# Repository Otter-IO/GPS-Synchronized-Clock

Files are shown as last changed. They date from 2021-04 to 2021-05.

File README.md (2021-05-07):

# GPS-Synchronized-Clock
This is an FPGA based GPS Synchronized Clock. It utilizes an Intel 10M02SCE144 single supply FPGA with integrated configuration memory.

The clock is split into 2 pieces, the FPGA board and the clock display. This was done so that to FPGA board could be used for other projects easily without redesign. It also allowed me to use a 4-layer board for the FPGA and a 2-layer board for the clock display. This helped keep costs low while also getting the advantages of a 4-layer board for the FPGA. The boards were designed using KiCAD.

The code is written in Verilog and is split into multiple modules to allow for easy modification and reuse. The bitstream files for the FPGA were generated using the free version of Intel Quartus Prime. The entire project is included for your use.

The code is by no means perfect. I’m still learning Verilog and there are certainly optimizations that could be made, especially with the SDC timing file. If you have more experience with FPGAs feel free to improve the design.

See the final product on YouTube: https://www.youtube.com/watch?v=TpDHRGk3vro

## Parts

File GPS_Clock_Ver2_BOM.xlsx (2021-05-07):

Ref | Value | Description | KiCAD Footprint
DS1 | 7_Segment | 0.56" CC Seven Segment Display | Custom_Parts:0.56_CC_7_Segment_Display
DS2 | 7_Segment | 0.56" CC Seven Segment Display | Custom_Parts:0.56_CC_7_Segment_Display
DS3 | 7_Segment | 0.56" CC Seven Segment Display | Custom_Parts:0.56_CC_7_Segment_Display
DS4 | 7_Segment | 0.56" CC Seven Segment Display | Custom_Parts:0.56_CC_7_Segment_Display
DS5 | 7_Segment | 0.56" CC Seven Segment Display | Custom_Parts:0.56_CC_7_Segment_Display
DS6 | 7_Segment | 0.56" CC Seven Segment Display | Custom_Parts:0.56_CC_7_Segment_Display
DS7 | 7_Segment | 0.56" CC Seven Segment Display | Custom_Parts:0.56_CC_7_Segment_Display
DS8 | 7_Segment | 0.56" CC Seven Segment Display | Custom_Parts:0.56_CC_7_Segment_Display
DS9 | 7_Segment | 0.56" CC Seven Segment Display | Custom_Parts:0.56_CC_7_Segment_Display
J2 | IO Pins | 2.54mm Female Pin Headers | Connector_PinHeader_2.54mm:PinHeader_2x20_P2.54mm_Vertical
J4 | IO Pins | 2.54mm Female Pin Headers | Connector_PinHeader_2.54mm:PinHeader_2x20_P2.54mm_Vertical
J3 | IO Pins | 2.54mm Female Pin Headers | Connector_PinHeader_2.54mm:PinHeader_2x14_P2.54mm_Vertical
J1 | 5V Power | 2.54mm Female Pin Headers | Connector_PinHeader_2.54mm:PinHeader_2x02_P2.54mm_Vertical
R1 | 220 | 0805 Resistor | Resistor_SMD:R_0805_2012Metric_Pad1.20x1.40mm_HandSolder
R3 | 220 | 0805 Resistor | Resistor_SMD:R_0805_2012Metric_Pad1.20x1.40mm_HandSolder
R5 | 220 | 0805 Resistor | Resistor_SMD:R_0805_2012Metric_Pad1.20x1.40mm_HandSolder
R7 | 220 | 0805 Resistor | Resistor_SMD:R_0805_2012Metric_Pad1.20x1.40mm_HandSolder
R8 | 220 | 0805 Resistor | Resistor_SMD:R_0805_2012Metric_Pad1.20x1.40mm_HandSolder
R10 | 220 | 0805 Resistor | Resistor_SMD:R_0805_2012Metric_Pad1.20x1.40mm_HandSolder
R17 | 220 | 0805 Resistor | Resistor_SMD:R_0805_2012Metric_Pad1.20x1.40mm_HandSolder
R12 | 220 | 0805 Resistor | Resistor_SMD:R_0805_2012Metric_Pad1.20x1.40mm_HandSolder
R14 | 220 | 0805 Resistor | Resistor_SMD:R_0805_2012Metric_Pad1.20x1.40mm_HandSolder
R19 | 220 | 0805 Resistor | Resistor_SMD:R_0805_2012Metric_Pad1.20x1.40mm_HandSolder
R21 | 220 | 0805 Resistor | Resistor_SMD:R_0805_2012Metric_Pad1.20x1.40mm_HandSolder
R23 | 220 | 0805 Resistor | Resistor_SMD:R_0805_2012Metric_Pad1.20x1.40mm_HandSolder
R24 | 220 | 0805 Resistor | Resistor_SMD:R_0805_2012Metric_Pad1.20x1.40mm_HandSolder
R26 | 220 | 0805 Resistor | Resistor_SMD:R_0805_2012Metric_Pad1.20x1.40mm_HandSolder
R33 | 220 | 0805 Resistor | Resistor_SMD:R_0805_2012Metric_Pad1.20x1.40mm_HandSolder
R28 | 220 | 0805 Resistor | Resistor_SMD:R_0805_2012Metric_Pad1.20x1.40mm_HandSolder
R30 | 220 | 0805 Resistor | Resistor_SMD:R_0805_2012Metric_Pad1.20x1.40mm_HandSolder
R35 | 220 | 0805 Resistor | Resistor_SMD:R_0805_2012Metric_Pad1.20x1.40mm_HandSolder
R37 | 220 | 0805 Resistor | Resistor_SMD:R_0805_2012Metric_Pad1.20x1.40mm_HandSolder
R39 | 220 | 0805 Resistor | Resistor_SMD:R_0805_2012Metric_Pad1.20x1.40mm_HandSolder
R40 | 220 | 0805 Resistor | Resistor_SMD:R_0805_2012Metric_Pad1.20x1.40mm_HandSolder
R42 | 220 | 0805 Resistor | Resistor_SMD:R_0805_2012Metric_Pad1.20x1.40mm_HandSolder
R44 | 220 | 0805 Resistor | Resistor_SMD:R_0805_2012Metric_Pad1.20x1.40mm_HandSolder
R46 | 220 | 0805 Resistor | Resistor_SMD:R_0805_2012Metric_Pad1.20x1.40mm_HandSolder
R48 | 220 | 0805 Resistor | Resistor_SMD:R_0805_2012Metric_Pad1.20x1.40mm_HandSolder
R50 | 220 | 0805 Resistor | Resistor_SMD:R_0805_2012Metric_Pad1.20x1.40mm_HandSolder
R52 | 220 | 0805 Resistor | Resistor_SMD:R_0805_2012Metric_Pad1.20x1.40mm_HandSolder
R54 | 220 | 0805 Resistor | Resistor_SMD:R_0805_2012Metric_Pad1.20x1.40mm_HandSolder
R55 | 220 | 0805 Resistor | Resistor_SMD:R_0805_2012Metric_Pad1.20x1.40mm_HandSolder
R57 | 220 | 0805 Resistor | Resistor_SMD:R_0805_2012Metric_Pad1.20x1.40mm_HandSolder
R59 | 220 | 0805 Resistor | Resistor_SMD:R_0805_2012Metric_Pad1.20x1.40mm_HandSolder
R61 | 220 | 0805 Resistor | Resistor_SMD:R_0805_2012Metric_Pad1.20x1.40mm_HandSolder
R62 | 220 | 0805 Resistor | Resistor_SMD:R_0805_2012Metric_Pad1.20x1.40mm_HandSolder
R64 | 220 | 0805 Resistor | Resistor_SMD:R_0805_2012Metric_Pad1.20x1.40mm_HandSolder
R66 | 220 | 0805 Resistor | Resistor_SMD:R_0805_2012Metric_Pad1.20x1.40mm_HandSolder
R68 | 220 | 0805 Resistor | Resistor_SMD:R_0805_2012Metric_Pad1.20x1.40mm_HandSolder
R2 | 220 | 0805 Resistor | Resistor_SMD:R_0805_2012Metric_Pad1.20x1.40mm_HandSolder
R4 | 220 | 0805 Resistor | Resistor_SMD:R_0805_2012Metric_Pad1.20x1.40mm_HandSolder
R6 | 220 | 0805 Resistor | Resistor_SMD:R_0805_2012Metric_Pad1.20x1.40mm_HandSolder
R9 | 220 | 0805 Resistor | Resistor_SMD:R_0805_2012Metric_Pad1.20x1.40mm_HandSolder
R11 | 220 | 0805 Resistor | Resistor_SMD:R_0805_2012Metric_Pad1.20x1.40mm_HandSolder
R13 | 220 | 0805 Resistor | Resistor_SMD:R_0805_2012Metric_Pad1.20x1.40mm_HandSolder
R18 | 220 | 0805 Resistor | Resistor_SMD:R_0805_2012Metric_Pad1.20x1.40mm_HandSolder
R20 | 220 | 0805 Resistor | Resistor_SMD:R_0805_2012Metric_Pad1.20x1.40mm_HandSolder
R22 | 220 | 0805 Resistor | Resistor_SMD:R_0805_2012Metric_Pad1.20x1.40mm_HandSolder
R25 | 220 | 0805 Resistor | Resistor_SMD:R_0805_2012Metric_Pad1.20x1.40mm_HandSolder
R27 | 220 | 0805 Resistor | Resistor_SMD:R_0805_2012Metric_Pad1.20x1.40mm_HandSolder
R29 | 220 | 0805 Resistor | Resistor_SMD:R_0805_2012Metric_Pad1.20x1.40mm_HandSolder
R34 | 220 | 0805 Resistor | Resistor_SMD:R_0805_2012Metric_Pad1.20x1.40mm_HandSolder
R36 | 220 | 0805 Resistor | Resistor_SMD:R_0805_2012Metric_Pad1.20x1.40mm_HandSolder
R38 | 220 | 0805 Resistor | Resistor_SMD:R_0805_2012Metric_Pad1.20x1.40mm_HandSolder
R41 | 220 | 0805 Resistor | Resistor_SMD:R_0805_2012Metric_Pad1.20x1.40mm_HandSolder
R43 | 220 | 0805 Resistor | Resistor_SMD:R_0805_2012Metric_Pad1.20x1.40mm_HandSolder
R45 | 220 | 0805 Resistor | Resistor_SMD:R_0805_2012Metric_Pad1.20x1.40mm_HandSolder
R49 | 220 | 0805 Resistor | Resistor_SMD:R_0805_2012Metric_Pad1.20x1.40mm_HandSolder
R51 | 220 | 0805 Resistor | Resistor_SMD:R_0805_2012Metric_Pad1.20x1.40mm_HandSolder
R53 | 220 | 0805 Resistor | Resistor_SMD:R_0805_2012Metric_Pad1.20x1.40mm_HandSolder
R56 | 220 | 0805 Resistor | Resistor_SMD:R_0805_2012Metric_Pad1.20x1.40mm_HandSolder
R58 | 220 | 0805 Resistor | Resistor_SMD:R_0805_2012Metric_Pad1.20x1.40mm_HandSolder
R60 | 220 | 0805 Resistor | Resistor_SMD:R_0805_2012Metric_Pad1.20x1.40mm_HandSolder
R63 | 220 | 0805 Resistor | Resistor_SMD:R_0805_2012Metric_Pad1.20x1.40mm_HandSolder
R65 | 220 | 0805 Resistor | Resistor_SMD:R_0805_2012Metric_Pad1.20x1.40mm_HandSolder
R67 | 220 | 0805 Resistor | Resistor_SMD:R_0805_2012Metric_Pad1.20x1.40mm_HandSolder
R47 | 220 | 0805 Resistor | Resistor_SMD:R_0805_2012Metric_Pad1.20x1.40mm_HandSolder
D1 | LED | 3mm LED | LED_THT:LED_D3.0mm
D2 | LED | 3mm LED | LED_THT:LED_D3.0mm
D3 | LED | 3mm LED | LED_THT:LED_D3.0mm
D4 | LED | 3mm LED | LED_THT:LED_D3.0mm
R15 | 220 | 0805 Resistor | Resistor_SMD:R_0805_2012Metric_Pad1.20x1.40mm_HandSolder
R16 | 220 | 0805 Resistor | Resistor_SMD:R_0805_2012Metric_Pad1.20x1.40mm_HandSolder
R31 | 220 | 0805 Resistor | Resistor_SMD:R_0805_2012Metric_Pad1.20x1.40mm_HandSolder
R32 | 220 | 0805 Resistor | Resistor_SMD:R_0805_2012Metric_Pad1.20x1.40mm_HandSolder
S1 | Tact_Switch | Generic Tact Switch | Custom_Parts:THT_Tact_Switch
S2 | Tact_Switch | Generic Tact Switch | Custom_Parts:THT_Tact_Switch
S3 | Tact_Switch | Generic Tact Switch | Custom_Parts:THT_Tact_Switch
R69 | 10k | 0603 Resistor | Resistor_SMD:R_0603_1608Metric_Pad0.98x0.95mm_HandSolder
R70 | 10k | 0603 Resistor | Resistor_SMD:R_0603_1608Metric_Pad0.98x0.95mm_HandSolder
R71 | 10k | 0603 Resistor | Resistor_SMD:R_0603_1608Metric_Pad0.98x0.95mm_HandSolder
J5 | GPS Module | Generic GPS Module (Get Pinout From PCB) | Connector_PinHeader_2.54mm:PinHeader_1x05_P2.54mm_Vertical
D5 | LED | 3mm LED | LED_THT:LED_D3.0mm
R72 | 220 | 0805 Resistor | Resistor_SMD:R_0805_2012Metric_Pad1.20x1.40mm_HandSolder

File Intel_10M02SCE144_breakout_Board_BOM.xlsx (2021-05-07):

Ref | Value | Description | KiCAD Footprint
C1 | 10uF | Electrolytic Through Hole Capacitor | Capacitor_THT:CP_Radial_D4.0mm_P2.00mm
C10 | 0.1uF | 0603 Ceramic Capacitor | Capacitor_SMD:C_0603_1608Metric_Pad1.08x0.95mm_HandSolder
C11 | 0.1uF | 0603 Ceramic Capacitor | Capacitor_SMD:C_0603_1608Metric_Pad1.08x0.95mm_HandSolder
C12 | 1uF | 0603 Ceramic Capacitor | Capacitor_SMD:C_0603_1608Metric_Pad1.08x0.95mm_HandSolder
C13 | 0.1uF | 0603 Ceramic Capacitor | Capacitor_SMD:C_0603_1608Metric_Pad1.08x0.95mm_HandSolder
C14 | 1uF | 0603 Ceramic Capacitor | Capacitor_SMD:C_0603_1608Metric_Pad1.08x0.95mm_HandSolder
C15 | 0.1uF | 0603 Ceramic Capacitor | Capacitor_SMD:C_0603_1608Metric_Pad1.08x0.95mm_HandSolder
C16 | 1uF | 0603 Ceramic Capacitor | Capacitor_SMD:C_0603_1608Metric_Pad1.08x0.95mm_HandSolder
C17 | 0.1uF | 0603 Ceramic Capacitor | Capacitor_SMD:C_0603_1608Metric_Pad1.08x0.95mm_HandSolder
C18 | 1uF | 0603 Ceramic Capacitor | Capacitor_SMD:C_0603_1608Metric_Pad1.08x0.95mm_HandSolder
C19 | 0.1uF | 0603 Ceramic Capacitor | Capacitor_SMD:C_0603_1608Metric_Pad1.08x0.95mm_HandSolder
C2 | 10uF | Electrolytic Through Hole Capacitor | Capacitor_THT:CP_Radial_D4.0mm_P2.00mm
C20 | 1uF | 0603 Ceramic Capacitor | Capacitor_SMD:C_0603_1608Metric_Pad1.08x0.95mm_HandSolder
C21 | 0.1uF | 0603 Ceramic Capacitor | Capacitor_SMD:C_0603_1608Metric_Pad1.08x0.95mm_HandSolder
C22 | 1uF | 0603 Ceramic Capacitor | Capacitor_SMD:C_0603_1608Metric_Pad1.08x0.95mm_HandSolder
C23 | 0.1uF | 0603 Ceramic Capacitor | Capacitor_SMD:C_0603_1608Metric_Pad1.08x0.95mm_HandSolder
C24 | 1uF | 0603 Ceramic Capacitor | Capacitor_SMD:C_0603_1608Metric_Pad1.08x0.95mm_HandSolder
C25 | 0.1uF | 0603 Ceramic Capacitor | Capacitor_SMD:C_0603_1608Metric_Pad1.08x0.95mm_HandSolder
C26 | 1uF | 0603 Ceramic Capacitor | Capacitor_SMD:C_0603_1608Metric_Pad1.08x0.95mm_HandSolder
C27 | 10pF | 0603 Ceramic Capacitor | Capacitor_SMD:C_0603_1608Metric_Pad1.08x0.95mm_HandSolder
C28 | 10pF | 0603 Ceramic Capacitor | Capacitor_SMD:C_0603_1608Metric_Pad1.08x0.95mm_HandSolder
C29 | 10pF | 0603 Ceramic Capacitor | Capacitor_SMD:C_0603_1608Metric_Pad1.08x0.95mm_HandSolder
C3 | 0.01uF | 0603 Ceramic Capacitor | Capacitor_SMD:C_0603_1608Metric_Pad1.08x0.95mm_HandSolder
C30 | 10pF | 0603 Ceramic Capacitor | Capacitor_SMD:C_0603_1608Metric_Pad1.08x0.95mm_HandSolder
C4 | 0.1uF | 0603 Ceramic Capacitor | Capacitor_SMD:C_0603_1608Metric_Pad1.08x0.95mm_HandSolder
C5 | 0.1uF | 0603 Ceramic Capacitor | Capacitor_SMD:C_0603_1608Metric_Pad1.08x0.95mm_HandSolder
C6 | 0.1uF | 0603 Ceramic Capacitor | Capacitor_SMD:C_0603_1608Metric_Pad1.08x0.95mm_HandSolder
C7 | 0.1uF | 0603 Ceramic Capacitor | Capacitor_SMD:C_0603_1608Metric_Pad1.08x0.95mm_HandSolder
C8 | 0.1uF | 0603 Ceramic Capacitor | Capacitor_SMD:C_0603_1608Metric_Pad1.08x0.95mm_HandSolder
C9 | 0.1uF | 0603 Ceramic Capacitor | Capacitor_SMD:C_0603_1608Metric_Pad1.08x0.95mm_HandSolder
D1 | POWER | 3mm LED | LED_THT:LED_D3.0mm
D2 | LED | 3mm LED | LED_THT:LED_D3.0mm
D3 | D_Schottky | 0603 Schottky diode | Diode_SMD:D_0603_1608Metric_Pad1.05x0.95mm_HandSolder
D4 | D_Schottky | 0603 Schottky diode | Diode_SMD:D_0603_1608Metric_Pad1.05x0.95mm_HandSolder
D5 | D_Schottky | 0603 Schottky diode | Diode_SMD:D_0603_1608Metric_Pad1.05x0.95mm_HandSolder
D6 | D_Schottky | 0603 Schottky diode | Diode_SMD:D_0603_1608Metric_Pad1.05x0.95mm_HandSolder
H1 | MountingHole | M3 Mounting Hole | MountingHole:MountingHole_3.2mm_M3
H2 | MountingHole | M3 Mounting Hole | MountingHole:MountingHole_3.2mm_M3
H3 | MountingHole | M3 Mounting Hole | MountingHole:MountingHole_3.2mm_M3
H4 | MountingHole | M3 Mounting Hole | MountingHole:MountingHole_3.2mm_M3
J1 | USB_B_Mini | USB Mini Type B connector | Custom_Parts:USB_Mini_Through_Hole
J2 | 5V POWER | 2.54mm Male Pin Headers | Connector_PinHeader_2.54mm:PinHeader_2x02_P2.54mm_Vertical
J3 | IO Pins | 2.54mm Male Pin Headers | Connector_PinHeader_2.54mm:PinHeader_2x20_P2.54mm_Vertical
J4 | IO Pins | 2.54mm Male Pin Headers | Connector_PinHeader_2.54mm:PinHeader_2x14_P2.54mm_Vertical
J5 | IO Pins | 2.54mm Male Pin Headers | Connector_PinHeader_2.54mm:PinHeader_2x20_P2.54mm_Vertical
J6 | JTAG | 2.54mm Male Pin Headers | Connector_PinHeader_2.54mm:PinHeader_2x05_P2.54mm_Vertical
PS1 | 3.3V LDO Regulator | SOT-223 3.3V Linear Regulator (PAM3110ABA330R) | Custom_Parts:SOT230P700X190-4N
R1 | 220 | 0603 Resistor | Resistor_SMD:R_0603_1608Metric_Pad0.98x0.95mm_HandSolder
R10 | 10k | 0603 Resistor | Resistor_SMD:R_0603_1608Metric_Pad0.98x0.95mm_HandSolder
R11 | 10k | 0603 Resistor | Resistor_SMD:R_0603_1608Metric_Pad0.98x0.95mm_HandSolder
R12 | 10k | 0603 Resistor | Resistor_SMD:R_0603_1608Metric_Pad0.98x0.95mm_HandSolder
R13 | 10k | 0603 Resistor | Resistor_SMD:R_0603_1608Metric_Pad0.98x0.95mm_HandSolder
R14 | 10k | 0603 Resistor | Resistor_SMD:R_0603_1608Metric_Pad0.98x0.95mm_HandSolder
R15 | 220 | 0603 Resistor | Resistor_SMD:R_0603_1608Metric_Pad0.98x0.95mm_HandSolder
R2 | 1k | 0603 Resistor | Resistor_SMD:R_0603_1608Metric_Pad0.98x0.95mm_HandSolder
R3 | 10k | 0603 Resistor | Resistor_SMD:R_0603_1608Metric_Pad0.98x0.95mm_HandSolder
R4 | 10k | 0603 Resistor | Resistor_SMD:R_0603_1608Metric_Pad0.98x0.95mm_HandSolder
R5 | 10k | 0603 Resistor | Resistor_SMD:R_0603_1608Metric_Pad0.98x0.95mm_HandSolder
R6 | 10k | 0603 Resistor | Resistor_SMD:R_0603_1608Metric_Pad0.98x0.95mm_HandSolder
R7 | 10k | 0603 Resistor | Resistor_SMD:R_0603_1608Metric_Pad0.98x0.95mm_HandSolder
R8 | 10k | 0603 Resistor | Resistor_SMD:R_0603_1608Metric_Pad0.98x0.95mm_HandSolder
R9 | 10k | 0603 Resistor | Resistor_SMD:R_0603_1608Metric_Pad0.98x0.95mm_HandSolder
S1 | RESET | Generic Tact Switch | Custom_Parts:THT_Tact_Switch
U1 | 10M02SCE144C8G | Intel 10M02SCE144C8G EQFP-144 FPGA | Intel_MAX10_FPGA:QFP50P2200X2200X165-144N
Y1 | 50MHz 3.3V | 7mmx5mm 50MHz 3.3V Clock Oscillator (XLH735050.000000X) | Custom_Parts:7x5_Crystal_Oscillator

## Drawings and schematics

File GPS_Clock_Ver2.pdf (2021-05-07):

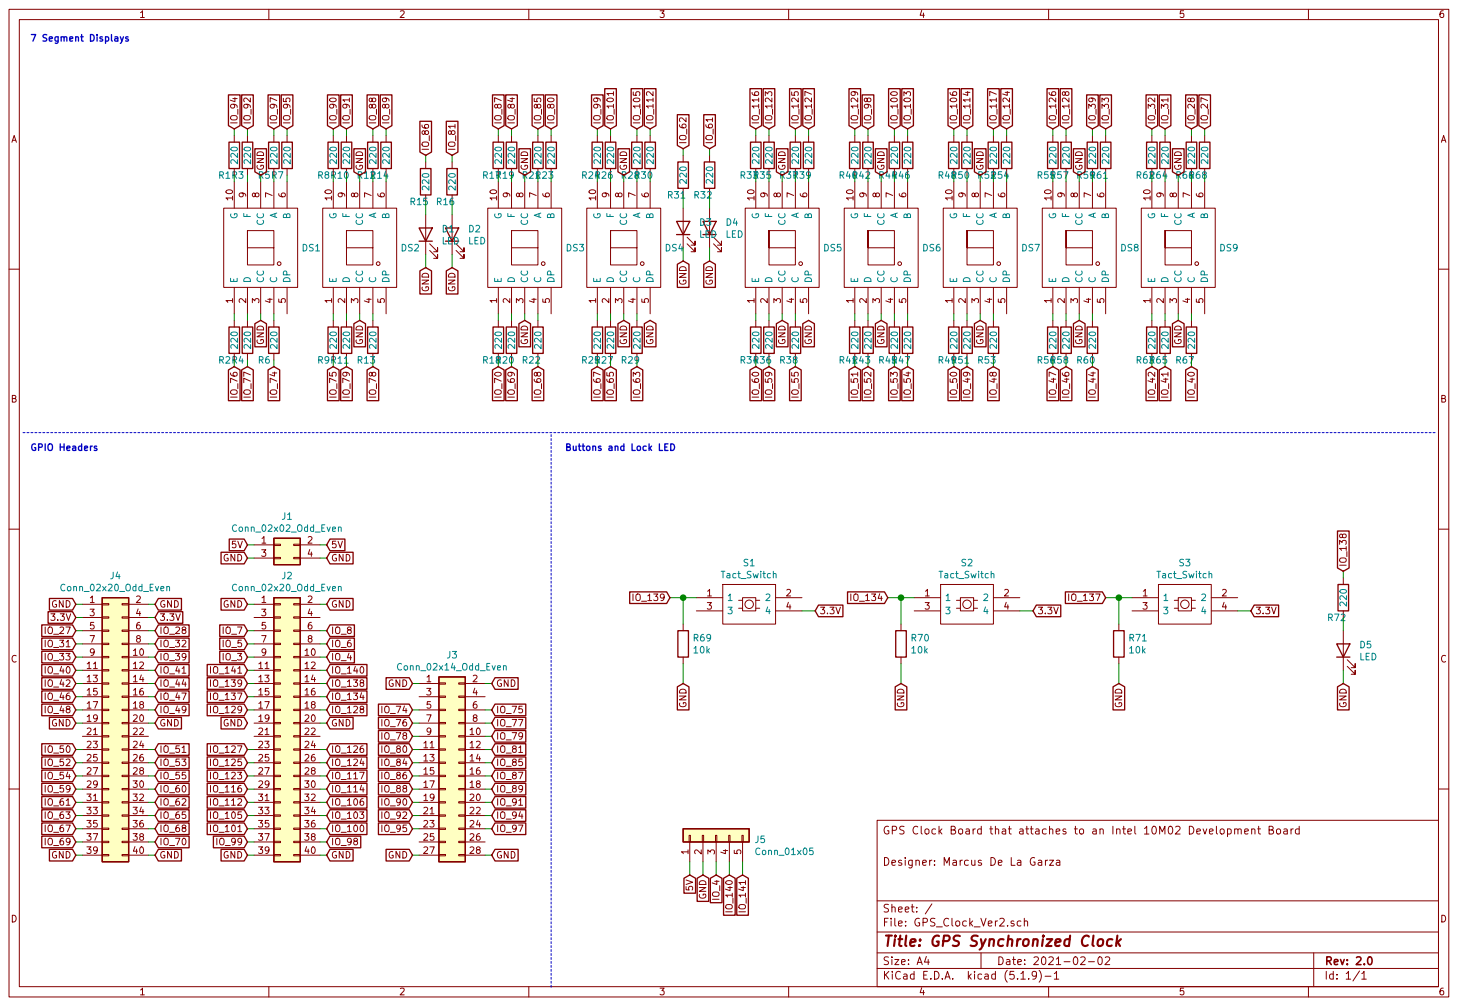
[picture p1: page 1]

GPS Clock Board that attaches to an Intel 10M02 Development Board

File: GPS_Clock_Ver2.sch Sheet: / Designer: Marcus De La Garza

Id: 1/1 Title: GPS Synchronized Clock

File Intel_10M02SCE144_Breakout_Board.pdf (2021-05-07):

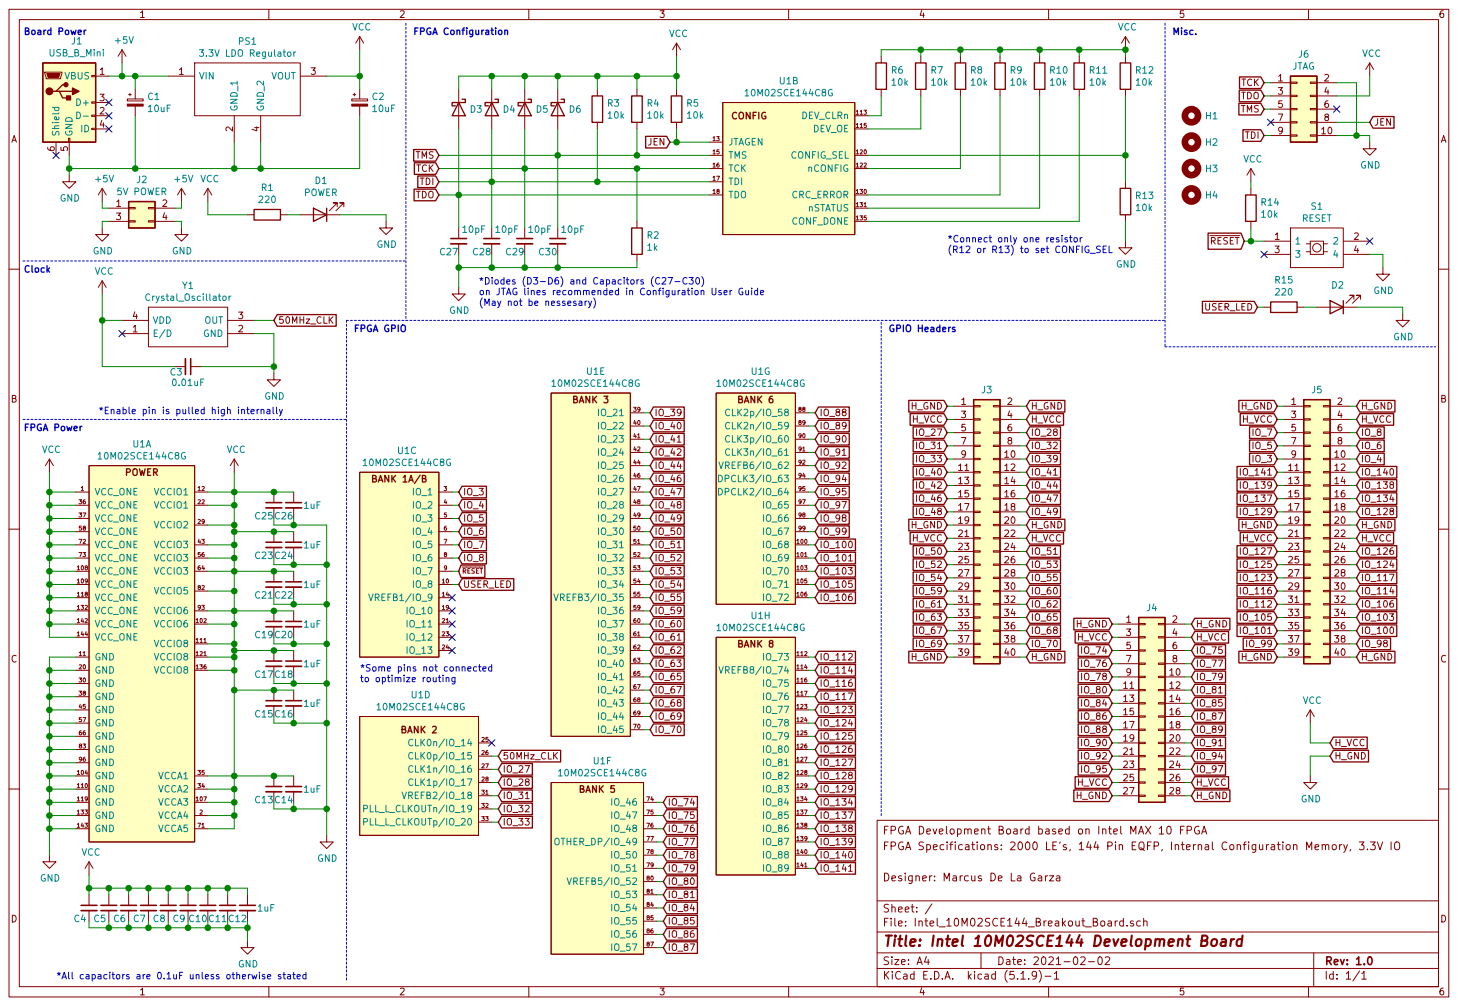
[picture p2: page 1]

(R12 or R13) to set CONFIG_SEL Board Power Clock

Misc. *Diodes (D3-D6) and Capacitors (C27-C30)

*Connect only one resistor

on JTAG lines recommended in Configuration User Guide
10M02SCE144C8G
BANK 3

*Enable pin is pulled high internally

to optimize routing FPGA Power

*Some pins not connected

FPGA Development Board based on Intel MAX 10 FPGA
FPGA Specifications: 2000 LE's, 144 Pin EQFP, Internal Configuration Memory, 3.3V IO

File: Intel_10M02SCE144_Breakout_Board.sch Sheet: / Designer: Marcus De La Garza

Id: 1/1 Title: Intel 10M02SCE144 Development Board

*All capacitors are 0.1uF unless otherwise stated

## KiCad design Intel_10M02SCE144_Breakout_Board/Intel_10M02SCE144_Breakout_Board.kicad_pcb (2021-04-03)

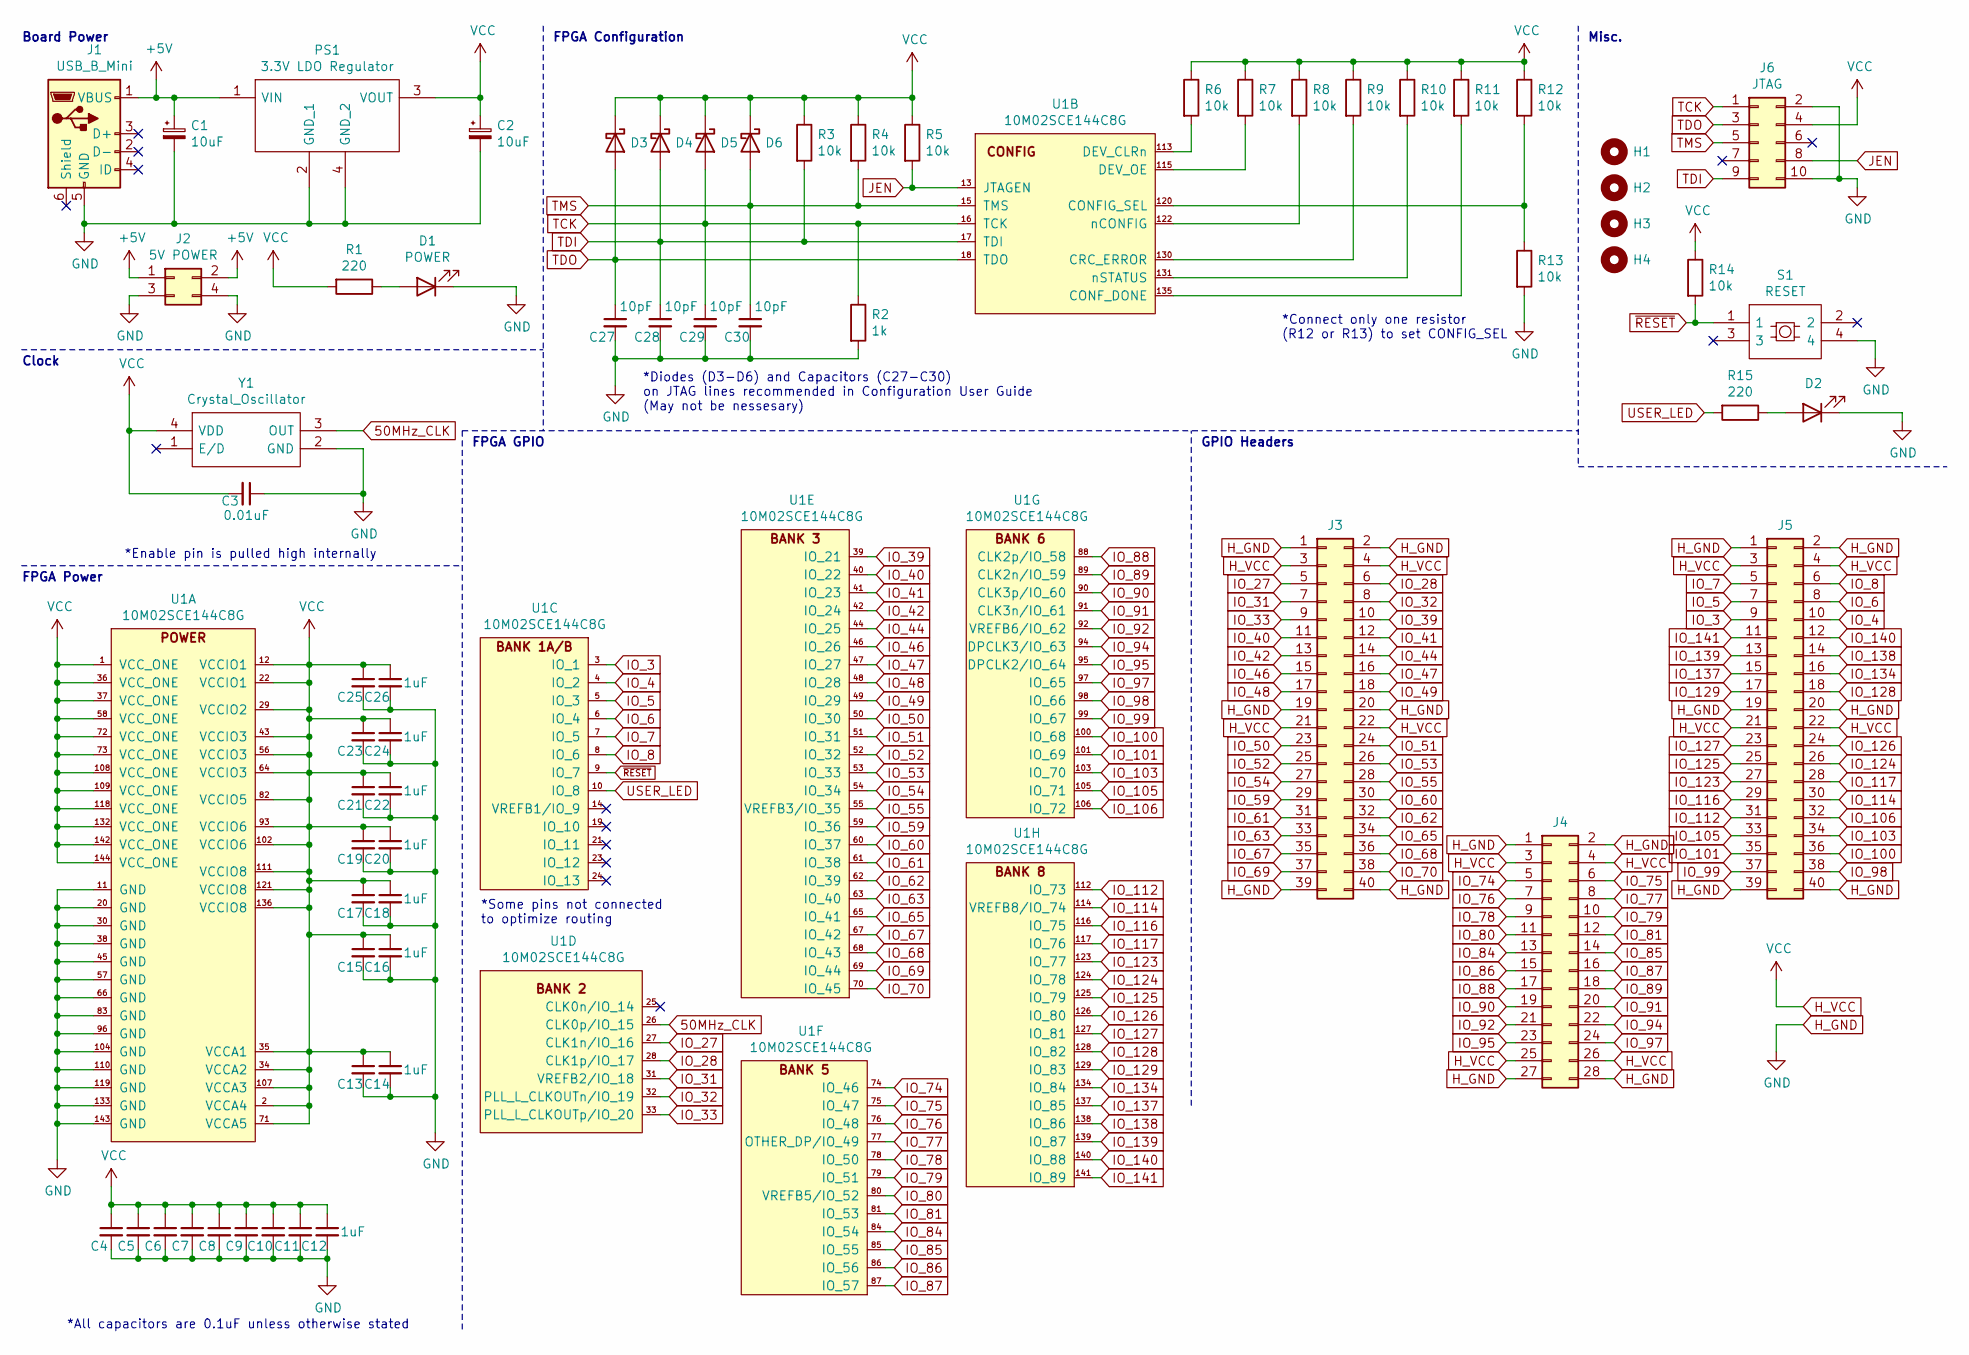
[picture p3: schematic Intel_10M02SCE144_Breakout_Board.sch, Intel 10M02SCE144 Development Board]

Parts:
C1, C2: 10uF; CP_Radial_D4.0mm_P2.00mm
C3: 0.01uF; C_0603_1608Metric_Pad1.08x0.95mm_HandSolder
C4, C5, C6, C7, C8, C9, C10, C11, C13, C15, C17, C19, C21, C23, C25: 0.1uF; C_0603_1608Metric_Pad1.08x0.95mm_HandSolder
C12, C14, C16, C18, C20, C22, C24, C26: 1uF; C_0603_1608Metric_Pad1.08x0.95mm_HandSolder
C27, C28, C29, C30: 10pF; C_0603_1608Metric_Pad1.08x0.95mm_HandSolder
D1: POWER; LED_D3.0mm
D2: LED; LED_D3.0mm
D3, D4, D5, D6: D_Schottky; D_0603_1608Metric_Pad1.05x0.95mm_HandSolder
H1, H2, H3, H4: MountingHole; MountingHole_3.2mm_M3
J1: USB_B_Mini; USB_Mini_Through_Hole
J2: 5V POWER; PinHeader_2x02_P2.54mm_Vertical
J3, J5: Conn_02x20_Odd_Even; PinHeader_2x20_P2.54mm_Vertical
J4: Conn_02x14_Odd_Even; PinHeader_2x14_P2.54mm_Vertical
J6: JTAG; PinHeader_2x05_P2.54mm_Vertical
PS1: 3.3V LDO Regulator; SOT230P700X190-4N
R1, R15: 220; R_0603_1608Metric_Pad0.98x0.95mm_HandSolder
R2: 1k; R_0603_1608Metric_Pad0.98x0.95mm_HandSolder
R3, R4, R5, R6, R7, R8, R9, R10, R11, R12, R13, R14: 10k; R_0603_1608Metric_Pad0.98x0.95mm_HandSolder
S1: RESET; THT_Tact_Switch
U1: 10M02SCE144C8G; QFP50P2200X2200X165-144N; Part Number 10M02SCE144C8G
Y1: Crystal_Oscillator; 7x5_Crystal_Oscillator

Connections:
50MHz_CLK: U1.26 (CLK0p/IO_15), Y1.3 (OUT)
+5V: C1.1, J1.1 (VBUS), J2.1, J2.2, PS1.1 (VIN)
H_GND: C1.2, C2.2, C3.1, C4.2, C5.2, C6.2, C7.2, C8.2, C9.2, C10.2, C11.2, C12.2, C13.2, C14.2, C15.2, C16.2, C17.2, C18.2, C19.2, C20.2, C21.2, C22.2, C23.2, C24.2, C25.2, C26.2, C27.2, C28.2, C29.2, C30.2, D1.1 (K), D2.1 (K), J1.5 (GND), J2.3, J2.4, J3.1, J3.2, J3.19, J3.20, J3.39, J3.40, J4.1, J4.2, J4.27, J4.28, J5.1, J5.2, J5.19, J5.20, J5.39, J5.40, J6.2, J6.10, PS1.2 (GND_1), PS1.4 (GND_2), R2.2, R13.2, S1.4, U1.11 (GND), U1.20 (GND), U1.30 (GND), U1.38 (GND), U1.45 (GND), U1.57 (GND), U1.66 (GND), U1.83 (GND), U1.96 (GND), U1.104 (GND), U1.110 (GND), U1.119 (GND), U1.133 (GND), U1.143 (GND), Y1.2 (GND)
H_VCC: C2.1, C3.2, C4.1, C5.1, C6.1, C7.1, C8.1, C9.1, C10.1, C11.1, C12.1, C13.1, C14.1, C15.1, C16.1, C17.1, C18.1, C19.1, C20.1, C21.1, C22.1, C23.1, C24.1, C25.1, C26.1, D3.1 (K), D4.1 (K), D5.1 (K), D6.1 (K), J3.3, J3.4, J3.21, J3.22, J4.3, J4.4, J4.25, J4.26, J5.3, J5.4, J5.21, J5.22, J6.4, PS1.3 (VOUT), R1.2, R3.1, R4.1, R5.1, R6.1, R7.1, R8.1, R9.1, R10.1, R11.1, R12.1, R14.1, U1.1 (VCC_ONE), U1.2 (VCCA4), U1.12 (VCCIO1), U1.22 (VCCIO1), U1.29 (VCCIO2), U1.34 (VCCA2), U1.35 (VCCA1), U1.36 (VCC_ONE), U1.37 (VCC_ONE), U1.43 (VCCIO3), U1.56 (VCCIO3), U1.58 (VCC_ONE), U1.64 (VCCIO3), U1.71 (VCCA5), U1.72 (VCC_ONE), U1.73 (VCC_ONE), U1.82 (VCCIO5), U1.93 (VCCIO6), U1.102 (VCCIO6), U1.107 (VCCA3), U1.108 (VCC_ONE), U1.109 (VCC_ONE), U1.111 (VCCIO8), U1.118 (VCC_ONE), U1.121 (VCCIO8), U1.132 (VCC_ONE), U1.136 (VCCIO8), U1.142 (VCC_ONE), U1.144 (VCC_ONE), Y1.4 (VDD)
IO_3: J5.9, U1.3 (IO_1)
IO_4: J5.10, U1.4 (IO_2)
IO_5: J5.7, U1.5 (IO_3)
IO_6: J5.8, U1.6 (IO_4)
IO_7: J5.5, U1.7 (IO_5)
IO_8: J5.6, U1.8 (IO_6)
IO_27: J3.5, U1.27 (CLK1n/IO_16)
IO_28: J3.6, U1.28 (CLK1p/IO_17)
IO_31: J3.7, U1.31 (VREFB2/IO_18)
IO_32: J3.8, U1.32 (PLL_L_CLKOUTn/IO_19)
IO_33: J3.9, U1.33 (PLL_L_CLKOUTp/IO_20)
IO_39: J3.10, U1.39 (IO_21)
IO_40: J3.11, U1.40 (IO_22)
IO_41: J3.12, U1.41 (IO_23)
IO_42: J3.13, U1.42 (IO_24)
IO_44: J3.14, U1.44 (IO_25)
IO_46: J3.15, U1.46 (IO_26)
IO_47: J3.16, U1.47 (IO_27)
IO_48: J3.17, U1.48 (IO_28)
IO_49: J3.18, U1.49 (IO_29)
IO_50: J3.23, U1.50 (IO_30)
IO_51: J3.24, U1.51 (IO_31)
IO_52: J3.25, U1.52 (IO_32)
IO_53: J3.26, U1.53 (IO_33)
IO_54: J3.27, U1.54 (IO_34)
IO_55: J3.28, U1.55 (VREFB3/IO_35)
IO_59: J3.29, U1.59 (IO_36)
IO_60: J3.30, U1.60 (IO_37)
IO_61: J3.31, U1.61 (IO_38)
IO_62: J3.32, U1.62 (IO_39)
IO_63: J3.33, U1.63 (IO_40)
IO_65: J3.34, U1.65 (IO_41)
IO_67: J3.35, U1.67 (IO_42)
IO_68: J3.36, U1.68 (IO_43)
IO_69: J3.37, U1.69 (IO_44)
IO_70: J3.38, U1.70 (IO_45)
IO_74: J4.5, U1.74 (IO_46)
IO_75: J4.6, U1.75 (IO_47)
IO_76: J4.7, U1.76 (IO_48)
IO_77: J4.8, U1.77 (OTHER_DP/IO_49)
IO_78: J4.9, U1.78 (IO_50)
IO_79: J4.10, U1.79 (IO_51)
IO_80: J4.11, U1.80 (VREFB5/IO_52)
IO_81: J4.12, U1.81 (IO_53)
IO_84: J4.13, U1.84 (IO_54)
IO_85: J4.14, U1.85 (IO_55)
IO_86: J4.15, U1.86 (IO_56)
IO_87: J4.16, U1.87 (IO_57)
IO_88: J4.17, U1.88 (CLK2p/IO_58)
IO_89: J4.18, U1.89 (CLK2n/IO_59)
IO_90: J4.19, U1.90 (CLK3p/IO_60)
IO_91: J4.20, U1.91 (CLK3n/IO_61)
IO_92: J4.21, U1.92 (VREFB6/IO_62)
IO_94: J4.22, U1.94 (DPCLK3/IO_63)
IO_95: J4.23, U1.95 (DPCLK2/IO_64)
IO_97: J4.24, U1.97 (IO_65)
IO_98: J5.38, U1.98 (IO_66)
IO_99: J5.37, U1.99 (IO_67)
IO_100: J5.36, U1.100 (IO_68)
IO_101: J5.35, U1.101 (IO_69)
IO_103: J5.34, U1.103 (IO_70)
IO_105: J5.33, U1.105 (IO_71)
IO_106: J5.32, U1.106 (IO_72)
IO_112: J5.31, U1.112 (IO_73)
IO_114: J5.30, U1.114 (VREFB8/IO_74)
IO_116: J5.29, U1.116 (IO_75)
IO_117: J5.28, U1.117 (IO_76)
IO_123: J5.27, U1.123 (IO_77)
IO_124: J5.26, U1.124 (IO_78)
IO_125: J5.25, U1.125 (IO_79)
IO_126: J5.24, U1.126 (IO_80)
IO_127: J5.23, U1.127 (IO_81)
IO_128: J5.18, U1.128 (IO_82)
IO_129: J5.17, U1.129 (IO_83)
IO_134: J5.16, U1.134 (IO_84)
IO_137: J5.15, U1.137 (IO_85)
IO_138: J5.14, U1.138 (IO_86)
IO_139: J5.13, U1.139 (IO_87)
IO_140: J5.12, U1.140 (IO_88)
IO_141: J5.11, U1.141 (IO_89)
JEN: J6.8, R5.2, U1.13 (JTAGEN)
unnamed: D1.2 (A), R1.1
unnamed: D2.2 (A), R15.1
unnamed: R6.2, U1.113 (DEV_CLRn)
unnamed: R7.2, U1.115 (DEV_OE)
unnamed: R8.2, U1.122 (nCONFIG)
unnamed: R9.2, U1.130 (CRC_ERROR)
unnamed: R10.2, U1.131 (nSTATUS)
unnamed: R11.2, U1.135 (CONF_DONE)
unnamed: R12.2, R13.1, U1.120 (CONFIG_SEL)
TCK: C29.1, D5.2 (A), J6.1, R2.1, U1.16 (TCK)
TDI: C28.1, D4.2 (A), J6.9, R3.2, U1.17 (TDI)
TDO: C27.1, D3.2 (A), J6.3, U1.18 (TDO)
TMS: C30.1, D6.2 (A), J6.5, R4.2, U1.15 (TMS)
USER_LED: R15.2, U1.10 (IO_8)
~RESET: R14.2, S1.1, U1.9 (IO_7)

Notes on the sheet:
*Enable pin is pulled high internally
*All capacitors are 0.1uF unless otherwise stated
*Connect only one resistor (R12 or R13) to set CONFIG_SEL
*Diodes (D3-D6) and Capacitors (C27-C30) on JTAG lines recommended in Configuration User Guide (May not be nessesary)
*Some pins not connected to optimize routing
Board Power
Clock
FPGA Power
FPGA GPIO
FPGA Configuration
GPIO Headers
Misc.

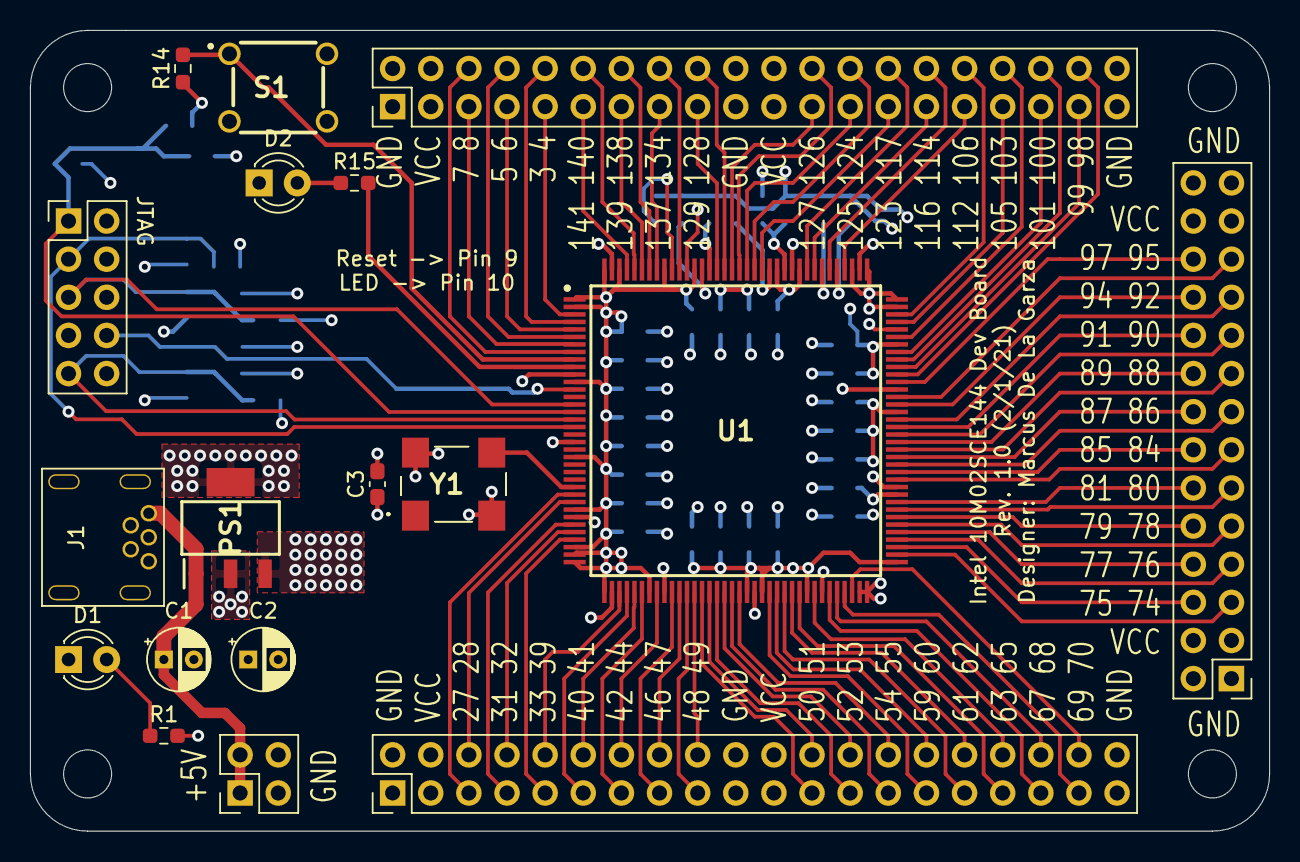
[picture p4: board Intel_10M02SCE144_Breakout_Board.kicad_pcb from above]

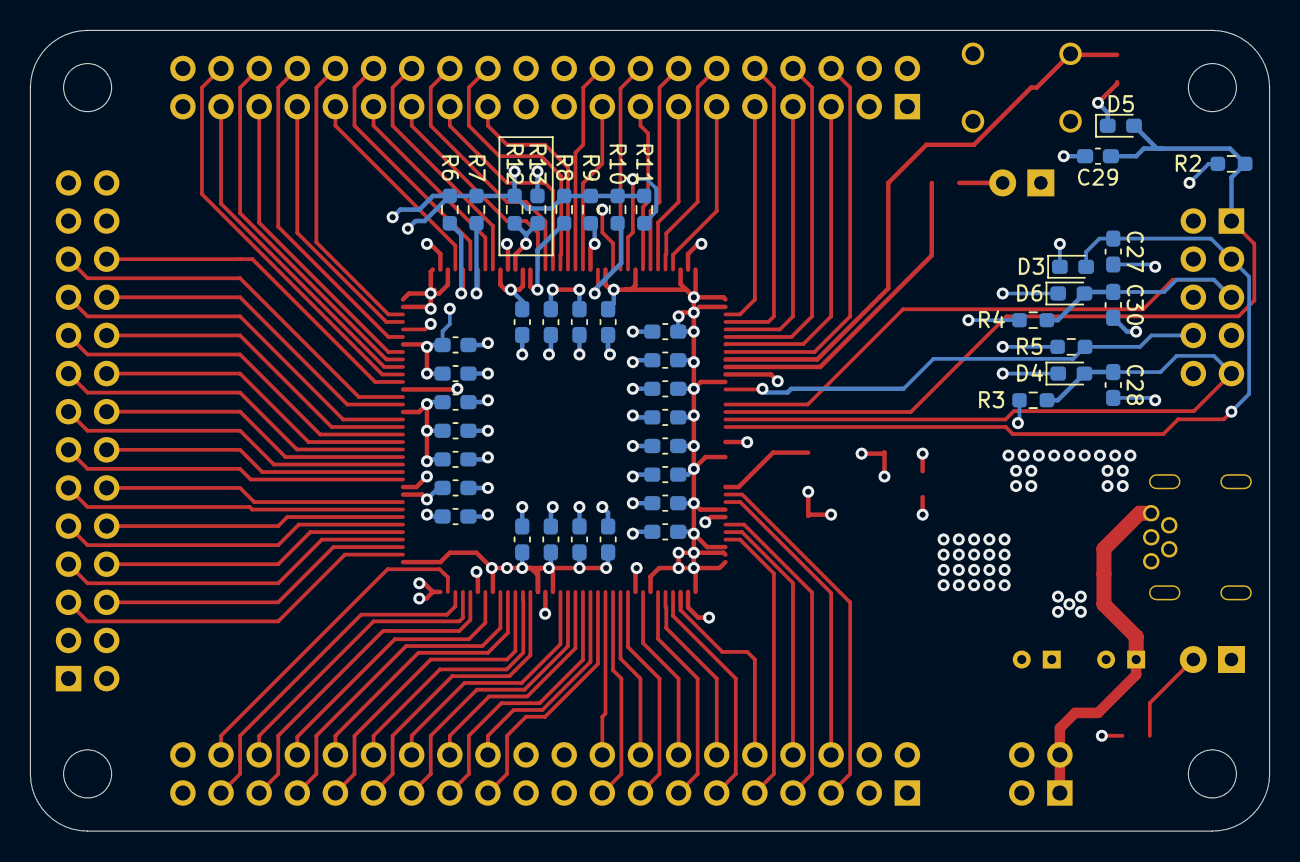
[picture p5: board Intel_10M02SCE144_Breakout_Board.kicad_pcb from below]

Board: 4 copper layers, 82.5 x 53.3 mm, 65 parts (43 on the bottom side), 100 nets.

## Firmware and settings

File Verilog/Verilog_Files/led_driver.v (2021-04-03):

// This module takes a number from 0-9 on the input and converts it to a 7 segment format on the output
// The display can be dimmed by creating a variable duty cycle on the on_signal input

module led_driver(
	input clk, // Clock Input
	input reset, // Reset Input
	input on_signal, // Toggles display on or off (0 = off, 1 = on)
	input wire[3:0] number, // Input for number to display (0-9)
	output reg[6:0] led_ff // Output registers to connect to display
);
	
	reg[6:0] led_next; // combinational register for each segment
	
	always @(posedge clk or negedge reset) begin // Set output register to combinational register
		if(reset == 0) begin
			led_ff <= 0;
		end else begin
			led_ff[0] <= led_next[0];
			led_ff[1] <= led_next[1];
			led_ff[2] <= led_next[2];
			led_ff[3] <= led_next[3];
			led_ff[4] <= led_next[4];
			led_ff[5] <= led_next[5];
			led_ff[6] <= led_next[6];
		end
	end
	
	always @(*) begin // Combinational logic
		case(on_signal)
			1'b0: begin // If on_signal is low turn off all segments
						led_next[0] = 0; led_next[1] = 0; led_next[2] = 0; led_next[3] = 0; led_next[4] = 0; led_next[5] = 0; led_next[6] = 0;
					end
			1'b1: begin // If on_signal is high set segments to correct output based on number input
						case(number)
							4'd0: begin led_next[0] = 1; led_next[1] = 1; led_next[2] = 1; led_next[3] = 1; led_next[4] = 1; led_next[5] = 1; led_next[6] = 0; end
							4'd1: begin led_next[0] = 0; led_next[1] = 1; led_next[2] = 1; led_next[3] = 0; led_next[4] = 0; led_next[5] = 0; led_next[6] = 0; end
							4'd2: begin led_next[0] = 1; led_next[1] = 1; led_next[2] = 0; led_next[3] = 1; led_next[4] = 1; led_next[5] = 0; led_next[6] = 1; end
							4'd3: begin led_next[0] = 1; led_next[1] = 1; led_next[2] = 1; led_next[3] = 1; led_next[4] = 0; led_next[5] = 0; led_next[6] = 1; end
							4'd4: begin led_next[0] = 0; led_next[1] = 1; led_next[2] = 1; led_next[3] = 0; led_next[4] = 0; led_next[5] = 1; led_next[6] = 1; end
							4'd5: begin led_next[0] = 1; led_next[1] = 0; led_next[2] = 1; led_next[3] = 1; led_next[4] = 0; led_next[5] = 1; led_next[6] = 1; end
							4'd6: begin led_next[0] = 1; led_next[1] = 0; led_next[2] = 1; led_next[3] = 1; led_next[4] = 1; led_next[5] = 1; led_next[6] = 1; end
							4'd7: begin led_next[0] = 1; led_next[1] = 1; led_next[2] = 1; led_next[3] = 0; led_next[4] = 0; led_next[5] = 0; led_next[6] = 0; end
							4'd8: begin led_next[0] = 1; led_next[1] = 1; led_next[2] = 1; led_next[3] = 1; led_next[4] = 1; led_next[5] = 1; led_next[6] = 1; end
							4'd9: begin led_next[0] = 1; led_next[1] = 1; led_next[2] = 1; led_next[3] = 0; led_next[4] = 0; led_next[5] = 1; led_next[6] = 1; end
							default: begin led_next[0] = 0; led_next[1] = 0; led_next[2] = 0; led_next[3] = 0; led_next[4] = 0; led_next[5] = 0; led_next[6] = 0; end
						endcase
					end
			default: begin
							led_next[0] = 0; led_next[1] = 0; led_next[2] = 0; led_next[3] = 0; led_next[4] = 0; led_next[5] = 0; led_next[6] = 0;
						end
		endcase
	end

endmodule

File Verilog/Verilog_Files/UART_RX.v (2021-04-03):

// This module converts serial data to parallel data

module UART_RX(
        uart_rx, 
        clk, 
        reset, 
        data_out, 
        new_data
    );
    
    input uart_rx; // Serial input from GPS module
    input clk;
    input reset;
    output new_data; // Flag to indicate new parallel data
    output[7:0] data_out; // Parallel data output
    
    reg new_data;
    reg[7:0] data_out;
    
    reg uart_sync; // Holds incoming serial to synchronize it
    reg uart_data; // Holds incoming serial to synchronize it
    reg[7:0] data_hold; // Holds the bits as they come in
    reg[2:0] bit_num; // Specifys what bit is currently being processed
    reg[1:0] state; // Holds current state
    reg[12:0] baud_count; // Counter for the baud rate
    
    parameter BAUD = 13'd5208; // 50MHz/9600Baud
    
    parameter CHECK_START = 2'd0; // Parameters for the state names
    parameter CENTER_BIT = 2'd1;
    parameter GET_DATA = 2'd2;
    parameter CHECK_STOP = 2'd3;
    
    always @(posedge clk or negedge reset) begin //synchronizer for incoming data
        if(reset == 0) begin
            uart_sync <= 1'b1;
            uart_data <= 1'b1;
        end else begin
            uart_sync <= uart_rx;
            uart_data <= uart_sync;
        end
    end

    always @(posedge clk or negedge reset) begin
        if(reset == 0) begin
            data_hold <= 8'b00000000;
            data_out <= 8'b00000000;
            bit_num <= 0;
            baud_count <= 0;
            new_data <= 0;
            state <= CHECK_START;
        end else begin
            case(state)
                CHECK_START: begin // Check for the start bit
                        bit_num <= 0;
                        new_data <= 0;
                        if(uart_data == 0) begin // If input goes low advance state
                            state <= CENTER_BIT;
                        end else begin
                            state <= CHECK_START;
                        end
                    end
                CENTER_BIT: begin
                        if(baud_count == (BAUD >> 1'b1)) begin // Get to the center of the start bit for accurate sampling
                            if(uart_data == 0) begin
                                state <= GET_DATA;
                                baud_count <= 0;
                            end else begin
                                state <= CHECK_START;
                            end
                        end else begin
                            baud_count <= baud_count + 1;
                            state <= CENTER_BIT;
                        end
                    end
                GET_DATA: begin
                        if(baud_count == BAUD) begin // Sample data and set appropriate bit in data_hold to that value
                            if(bit_num == 7) begin
                                data_hold[bit_num] <= uart_data;
                                baud_count <= 0;
                                state <= CHECK_STOP;
                            end else if(bit_num >= 0) begin
                                data_hold[bit_num] <= uart_data;
                                baud_count <= 0;
                                bit_num <= bit_num + 1;
                            end
                        end else begin
                            baud_count <= baud_count + 1;
                            state <= GET_DATA;
                        end
                    end
                CHECK_STOP: begin // Send the stop bit
                        if(baud_count == BAUD) begin
                            state <= CHECK_START;
                            baud_count <= 0;
                        end else begin
                            data_out <= data_hold;
                            new_data <= 1;
                            baud_count <= baud_count + 1;
                        end
                    end
            endcase
        end
    end
endmodule
